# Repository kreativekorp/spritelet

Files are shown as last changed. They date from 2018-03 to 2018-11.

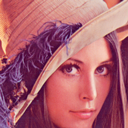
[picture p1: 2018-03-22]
testbuilds/userland/lena128.png

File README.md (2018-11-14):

# Spritelet v2

A Spritelet is a small box with a 128 x 128 pixel LCD screen for playing animations.

The Spritelet v2 software includes four applications:

  *  Clouds: Weather formations from a kingdom on shrooms drift past the screen.
  *  Carousel: The main application. Displays animations and static images from an SD card.
  *  dX: An overengineered electronic dice roller with hundreds of types of dice.
  *  Toasters: Airborne kitchen appliances with wings fly past the screen.

To make a Spritelet you will need the following hardware:

  *  One of the supported microcontroller boards.
  *  [Adafruit 1.44" Color TFT LCD Display w/ MicroSD](https://www.adafruit.com/product/2088)
  *  [Adafruit LiPoly Backpack Addon for Pro Trinket](https://www.adafruit.com/product/2124)
  *  [Lithium Ion Polymer Battery 3.7V 150mAh](https://www.adafruit.com/product/1317)
  *  [Fast Vibration Sensor Switch](https://www.adafruit.com/product/1766)
  *  [SPDT Slide Switch](https://www.adafruit.com/product/805)
  *  [Thru-Hole 5-Way Navigation Switch](https://www.adafruit.com/product/504)
  *  [SD/MicroSD Memory Card](https://www.adafruit.com/product/1294)
  *  An interconnect board to connect all the above together.
  *  [3D-Printed Spritelet v2 Enclosure](https://www.shapeways.com/model/upload-and-buy/7529582)
  *  [4x Machine Screw #4-40](https://www.digikey.com/product-detail/en/pomona-electronics/4862/501-1531-ND/745091)

Any of these supported microcontroller boards can be used:

  *  [Arduino Nano](#arduino-nano) (not recommended)
  *  [Teensy 3.1/3.2](#teensy-3132lc)
  *  [Teensy LC](#teensy-3132lc)
  *  [Adafruit Pro Trinket](#adafruit-pro-trinket)
  *  [Adafruit ItsyBitsy 32u4](#adafruit-itsybitsy-32u4)
  *  [Adafruit ItsyBitsy M0 Express](#adafruit-itsybitsy-m0-express)

You can of course use any board supported by the Arduino IDE with enough memory and pins, but without an appropriate interconnect board you won't be able to turn it into a finished product. Also, any board larger than an Arduino Nano will not fit inside the enclosure.

Assembly is reasonably self-explanatory except for the following caveats:

  *  Solder all other components *before* soldering the LCD display board! Otherwise the LCD display board will block soldering the other components.
  *  Separate the LCD display board from the interconnect board with electrical tape or a piece of cardboard to prevent the MicroSD card connector from shorting the navigation switch.
  *  On Arduino Nano boards, you will need to solder a wire from the VUSB hole of the interconnect board to the VCC pin of the USB connector.
  *  On Teensy boards, you will need to cut the jumper on the back to separate VIN from VUSB.
  *  On the LiPoly Backpack Addon, you will need to cut the trace between the two holes with a box around them to add an on/off switch.

The MicroSD card will need to contain the contents of the [userland](userland) directory. To add images and animations, use the SpriteLoader application (just dragging files into the SPRITES directory will not work).

## Arduino Nano

  *  Store link: https://store.arduino.cc/usa/arduino-nano
  *  Firmware: [spritelet2_protrinket](spritelet2_protrinket) (Arduino Nano and Pro Trinket use the same firmware)
  *  Interconnect board files: [board-nano](board-nano)
  *  Interconnect board purchase link: https://aisler.net/p/DWZPRWWS
  *  On Arduino Nano boards, you will need to solder a wire from the VUSB hole of the interconnect board to the VCC pin of the USB connector.

Pin mapping:

| Function | Pin | Port | Function | Pin | Port |
| --- | --- | ---- | --- | --- | ---- |
| SCK | 13  | PB5  | VS GND |  4  | PD4  |
| MISO | 12  | PB4  | VS POS |  3  | PD3  |
| MOSI | 11  | PB3  | JOY COM  | A0  | PC0  |
| TFT CS | 10  | PB2  | JOY CTR  | A1  | PC1  |
| TFT D/C  |  8  | PB0  | JOY UP | A2  | PC2  |
| TFT RST  |  6  | PD6  | JOY DN | A3  | PC3  |
| TFT LITE |  9  | PB1  | JOY LT | A4  | PC4  |
| SD CS |  5  | PD5  | JOY RT | A5  | PC5  |

## Teensy 3.1/3.2/LC

  *  Store link (3.1/3.2): https://www.pjrc.com/teensy/teensy31.html
  *  Store link (LC): https://www.pjrc.com/teensy/teensyLC.html
  *  Firmware: [spritelet2_teensy](spritelet2_teensy)
  *  Interconnect board files: [board-teensy](board-teensy)
  *  Interconnect board purchase link: https://aisler.net/p/WDFHSKDK
  *  On Teensy boards, you will need to cut the jumper on the back to separate VIN from VUSB.

Pin mapping:

| Function | Pin | Function | Pin |
| --- | --- | --- | --- |
| SCK | 13  | VS GND |  4  |
| MISO | 12  | VS POS |  3  |
| MOSI | 11  | JOY COM  | 14  |
| TFT CS | 10  | JOY CTR  | 19  |
| TFT D/C  |  8  | JOY UP | 18  |
| TFT RST  |  9  | JOY DN | 15  |
| TFT LITE |  5  | JOY LT | 17  |
| SD CS |  6  | JOY RT | 16  |

## Adafruit Pro Trinket

  *  Store link: https://www.adafruit.com/product/2000
  *  Firmware: [spritelet2_protrinket](spritelet2_protrinket)
  *  Interconnect board files: [board-protrinket](board-protrinket)
  *  Interconnect board purchase link: https://aisler.net/p/WMPMXXAI

Pin mapping:

| Function | Pin | Port | Function | Pin | Port |
| --- | --- | ---- | --- | --- | ---- |
| SCK | 13  | PB5  | VS GND |  4  | PD4  |
| MISO | 12  | PB4  | VS POS |  3  | PD3  |
| MOSI | 11  | PB3  | JOY COM  | A0  | PC0  |
| TFT CS | 10  | PB2  | JOY CTR  | A1  | PC1  |
| TFT D/C  |  8  | PB0  | JOY UP | A2  | PC2  |
| TFT RST  |  6  | PD6  | JOY DN | A3  | PC3  |
| TFT LITE |  9  | PB1  | JOY LT | A4  | PC4  |
| SD CS |  5  | PD5  | JOY RT | A5  | PC5  |

## Adafruit ItsyBitsy 32u4

  *  Store link: https://www.adafruit.com/product/3677
  *  Firmware: [spritelet2_itsybitsy_32u4](spritelet2_itsybitsy_32u4)
  *  Interconnect board files: [board-itsybitsy](board-itsybitsy)
  *  Interconnect board purchase link: https://aisler.net/p/JNFEJXOJ

Pin mapping:

| Function | Pin  | Port | Function | Pin  | Port |
| --- | ---- | ---- | --- | ---- | ---- |
| SCK | SCK  | PB1  | VS GND |  5 | PC6  |
| MISO | MISO | PB3  | VS POS |  7 | PE6  |
| MOSI | MOSI | PB2  | JOY COM  | A0 | PF7  |
| TFT CS |  9 | PB5  | JOY CTR  | A1 | PF6  |
| TFT D/C  | 11 | PB7  | JOY UP | A2 | PF5  |
| TFT RST  | 10 | PB6  | JOY DN | A3 | PF4  |
| TFT LITE | 13 | PC7  | JOY LT | A4 | PF1  |
| SD CS | 12 | PD6  | JOY RT | A5 | PF0  |

## Adafruit ItsyBitsy M0 Express

  *  Store link: https://www.adafruit.com/product/3727
  *  Firmware: [spritelet2_itsybitsy_m0](spritelet2_itsybitsy_m0)
  *  Interconnect board files: [board-itsybitsy](board-itsybitsy)
  *  Interconnect board purchase link: https://aisler.net/p/JNFEJXOJ

Pin mapping:

| Function | Pin  | Function | Pin  |
| --- | ---- | --- | ---- |
| SCK | SCK  | VS GND |  5 |
| MISO | MISO | VS POS |  7 |
| MOSI | MOSI | JOY COM  | A0 |
| TFT CS |  9 | JOY CTR  | A1 |
| TFT D/C  | 11 | JOY UP | A2 |
| TFT RST  | 10 | JOY DN | A3 |
| TFT LITE | 13 | JOY LT | A4 |
| SD CS | 12 | JOY RT | A5 |

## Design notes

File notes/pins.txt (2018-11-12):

Pin         Trinket     Teensy      ItsyBitsy
----------- ----------- ----------- -----------
SCK         13 (PB5)    13          SCK  (PB1)
MISO        12 (PB4)    12          MISO (PB3)
MOSI        11 (PB3)    11          MOSI (PB2)
SS          10 (PB2)    10          SS   (PB0)
----------- ----------- ----------- -----------
TFT CS      10 (PB2)    10           9 (PB5)
TFT D/C      8 (PB0)     8          11 (PB7)
TFT RST      6 (PD6)     9          10 (PB6)
TFT LITE     9 (PB1)     5          13 (PC7)
SD CS        5 (PD5)     6          12 (PD6)
----------- ----------- ----------- -----------
VS GND       4 (PD4)     4           5 (PC6)
VS POS       3 (PD3)     3           7 (PE6)
----------- ----------- ----------- -----------
JOY COM     A0 (PC0)    14          A0 (PF7)
JOY CTR     A1 (PC1)    19          A1 (PF6)
JOY UP      A2 (PC2)    18          A2 (PF5)
JOY DN      A3 (PC3)    15          A3 (PF4)
JOY LT      A4 (PC4)    17          A4 (PF1)
JOY RT      A5 (PC5)    16          A5 (PF0)

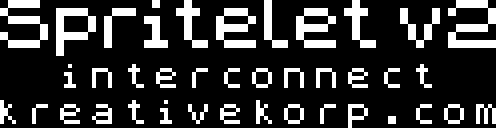
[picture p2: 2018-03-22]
board/spriteletv2.png

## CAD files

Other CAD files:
enclosure/s2enclosure2.skp

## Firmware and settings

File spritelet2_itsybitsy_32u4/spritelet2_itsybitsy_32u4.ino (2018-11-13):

#include <Arduino.h>
#include <avr/pgmspace.h>
#include <avr/power.h>
#include "carousel.h"
#include "clouds.h"
#include "dx.h"
#include "picofs_diskio.h"
#include "picofs_pins.h"
#include "picofs.h"
#include "spi.h"
#include "spritelet_bitmap.h"
#include "spritelet_font.h"
#include "spritelet_input.h"
#include "spritelet_pins.h"
#include "spritelet_util.h"
#include "st7735_commands.h"
#include "st7735_config.h"
#include "st7735_init.h"
#include "st7735_pins.h"
#include "st7735.h"
#include "toasters.h"

ST7735 tft = ST7735();
FATFS fs = FATFS();
static uint8_t index = 0;

static const char * const PROGMEM mount_failed[] = { "Please insert", "MicroSD card." };
static const char * const PROGMEM defaults_path = "DEFAULTS.SYS";
static const char * const PROGMEM home_menu_title = "Home";

#define HOME_MENU_ITEMS 4
static const char * const PROGMEM home_menu_items[] = {
  "Clouds",
  "Carousel",
  "dX",
  "Toasters",
};

void setup(void) {
  randomSeed(analogRead(2));
  power_adc_disable();
  power_twi_disable();
  power_usart0_disable();
  power_timer1_disable();
  power_timer2_disable();

  input_init();
  tft.init(true);
  tft.fillScreen(0);
  tft.setBacklight(1);

  fs.init(false);
  if (fs.mount()) {
    tft_drawString(25, 52, (char *)mount_failed[0], 0, -1);
    tft_drawString(25, 64, (char *)mount_failed[1], 0, -1);
    do { delay(500); } while (fs.mount());
    tft.fillScreen(0);
  }

  if (!fs.open((char *)defaults_path)) {
    if (!fs.read()) {
      index = fs.buf[0];
    }
    fs.close();
  }
}

void loop(void) {
  switch (index) {
    case 0: if (clouds_setup()) while (clouds_loop()); break;
    case 1: if (carousel_setup()) while (carousel_loop()); break;
    case 2: if (dx_setup()) while (dx_loop()); break;
    case 3: if (toasters_setup()) while (toasters_loop()); break;
  }

  home_menu();

  if (!fs.open((char *)defaults_path)) {
    uint16_t ptr;
    fs.buf[0] = index;
    for (ptr = 1; ptr < 512; ptr++) fs.buf[ptr] = -1;
    fs.write();
    fs.close();
  }
}

static void render_home_menu(uint8_t mask) {
  uint8_t m; uint16_t y, i, clr;
  // Draw Header
  if (mask & 0x80) {
    tft.fillRect(0, 0, 128, 16, 0x000F);
    tft_drawString(4, 2, (char *)home_menu_title, 0x000F, 0xFFFF);
  }
  // Draw Menu Items
  for (m = 0x40, y = 16, i = 0; i < HOME_MENU_ITEMS; m >>= 1, y += 16, i++) {
    if (mask & m) {
      clr = ((i == index) ? 0xC000 : 0x0000);
      tft.fillRect(0, y, 128, 16, clr);
      tft_drawString(4, y + 2, (char *)home_menu_items[i], clr, 0xFFFF);
    }
  }
}

static void home_menu() {
  uint8_t in_menu = 1, j;
  render_home_menu(0xFF);
  while (in_menu) {
    if ((j = input_get())) {
      switch (j) {
        case INPUT_UP:
        case INPUT_LT:
          index = (index > 0) ? (index - 1) : (HOME_MENU_ITEMS - 1);
          render_home_menu(0x7F);
          break;
        case INPUT_DN:
        case INPUT_RT:
          index = (index < (HOME_MENU_ITEMS - 1)) ? (index + 1) : 0;
          render_home_menu(0x7F);
          break;
        case INPUT_CTR:
          tft.fillScreen(0);
          in_menu = 0;
          break;
        default:
          continue;
      }
      delay(50);
      while (input_get());
      delay(50);
    }
  }
}

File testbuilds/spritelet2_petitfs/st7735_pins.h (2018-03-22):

/**************************************************************************/
/* ST7735 Driver Library for Adafruit 1.44" TFT Breakout with SD Card.    */
/* Based on Adafruit_ST7735_Library but stripped down and with bug fixes. */
/* Written by Rebecca Bettencourt. MIT license.                           */
/**************************************************************************/

#ifndef __ST7735_PINS__
#define __ST7735_PINS__

#include <Arduino.h>

// Chip select line for TFT display.
#define TFT_CS        10
#define TFT_CS_DDR    DDRB
#define TFT_CS_PORT   PORTB
#define TFT_CS_PIN    PINB
#define TFT_CS_MASK   0x04

// Data/command line for TFT display.
#define TFT_DC        8
#define TFT_DC_DDR    DDRB
#define TFT_DC_PORT   PORTB
#define TFT_DC_PIN    PINB
#define TFT_DC_MASK   0x01

// Reset line for TFT display.
#define TFT_RST       6
#define TFT_RST_DDR   DDRD
#define TFT_RST_PORT  PORTD
#define TFT_RST_PIN   PIND
#define TFT_RST_MASK  0x40

// Backlight pin for TFT display.
#define TFT_LITE      9
#define TFT_LITE_DDR  DDRB
#define TFT_LITE_PORT PORTB
#define TFT_LITE_PIN  PINB
#define TFT_LITE_MASK 0x02

// Chip select line for SD card.
#define SD_CS         5
#define SD_CS_DDR     DDRD
#define SD_CS_PORT    PORTD
#define SD_CS_PIN     PIND
#define SD_CS_MASK    0x20

#endif

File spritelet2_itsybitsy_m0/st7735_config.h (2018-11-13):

/**************************************************************************/
/* ST7735 Driver Library for Adafruit 1.44" TFT Breakout with SD Card.    */
/* Based on Adafruit_ST7735_Library but stripped down and with bug fixes. */
/* Written by Rebecca Bettencourt. MIT license.                           */
/**************************************************************************/

#ifndef __ST7735_CONFIG__
#define __ST7735_CONFIG__

#include "st7735_commands.h"

#define ST7735_TFTWIDTH  128
#define ST7735_TFTHEIGHT 128

#define ST7735_R0_MADCTL (MADCTL_MX | MADCTL_MY | MADCTL_BGR)
#define ST7735_R0_XSTART 2
#define ST7735_R0_YSTART 3

#define ST7735_R1_MADCTL (MADCTL_MY | MADCTL_MV | MADCTL_BGR)
#define ST7735_R1_XSTART 3
#define ST7735_R1_YSTART 2

#define ST7735_R2_MADCTL (MADCTL_BGR)
#define ST7735_R2_XSTART 2
#define ST7735_R2_YSTART 1

#define ST7735_R3_MADCTL (MADCTL_MX | MADCTL_MV | MADCTL_BGR)
#define ST7735_R3_XSTART 1
#define ST7735_R3_YSTART 2

#endif

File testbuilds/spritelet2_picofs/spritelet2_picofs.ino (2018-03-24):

#include <Arduino.h>
#include <SPI.h>
#include <avr/pgmspace.h>
#include <avr/power.h>
#include "clouds.h"
#include "picofs_diskio.h"
#include "picofs_pins.h"
#include "picofs.h"
#include "spritelet_font.h"
#include "spritelet_input.h"
#include "spritelet_pins.h"
#include "st7735_commands.h"
#include "st7735_config.h"
#include "st7735_init.h"
#include "st7735_pins.h"
#include "st7735.h"

ST7735 tft = ST7735();
FATFS fs = FATFS();

void setup(void) {
	randomSeed(analogRead(2));
	power_adc_disable();
	power_twi_disable();
	power_usart0_disable();
	power_timer1_disable();
	power_timer2_disable();

	input_init();
	tft.init(true);
	tft.fillScreen(0);
	tft.setBacklight(1);

	fs.init(false);
	if (fs.mount()) {
		tft_drawString(25, 52, "Please insert", 0, -1);
		tft_drawString(25, 64, "microSD card.", 0, -1);
		do { delay(500); } while (fs.mount());
		tft.fillScreen(0);
	}

	clouds_setup();
}

void loop(void) {
	uint32_t t = millis();
	clouds_loop();
	do {
		switch (input_get()) {
			case INPUT_UP: delay(200); while (input_get()); tft.setRotation(3); tft.fillScreen(0x6C3F); break;
			case INPUT_DN: delay(200); while (input_get()); tft.setRotation(1); tft.fillScreen(0x6C3F); break;
			case INPUT_LT: delay(200); while (input_get()); tft.setRotation(2); tft.fillScreen(0x6C3F); break;
			case INPUT_RT: delay(200); while (input_get()); tft.setRotation(0); tft.fillScreen(0x6C3F); break;
			case INPUT_CTR: delay(200); while (input_get()); lena(); clouds_setup(); break;
		}
	} while (millis() - t < 30);
}

void lena(void) {
	uint16_t ptr;
	if (!fs.open("LENA128.565")) {
		tft.setRotation(0);
		tft.setAddrWindow(0, 0, 127, 127);
		while (!fs.read()) {
			TFT_DC_PORT |=  TFT_DC_MASK;
			TFT_CS_PORT &=~ TFT_CS_MASK;
			for (ptr = 0; ptr < 512; ptr++) {
				SPI.transfer(fs.buf[ptr]);
			}
			TFT_CS_PORT |=  TFT_CS_MASK;
		}
		fs.close();
		while (!input_get());
		delay(200);
		while (input_get());
	}
}

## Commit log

2018-03-22 Initial import
    [spritelet2intercon.fzz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]
2018-03-24 Optimized? SPI library
2018-03-29 Version using Teensy LC
    [spritelet2-teensy.fzz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]
2018-11-10 3d model for enclosure
    [s2enclosure2.skp]
2018-11-11 Version for Teensy
2018-11-11 rename original board to specify pro trinket
    [spritelet2-protrinket.fzz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]
2018-11-12 Revised boards
    [spritelet2-itsybitsy.fzz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]
2018-11-13 Teensy fixes
2018-11-13 board for Arduino Nano version
    [spritelet2-nano.fzz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]
2018-11-13 split boards into separate dirs
    [spritelet2-itsybitsy.fzz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]
2018-12-16 Bigger holes for navigation switch
    [spritelet2-itsybitsy.fzz, spritelet2-nano.fzz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]
